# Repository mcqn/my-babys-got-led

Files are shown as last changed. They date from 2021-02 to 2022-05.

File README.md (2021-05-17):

# My Babys Got LED

An ESP8266 board to drive Neopixel/WS2812 LED strips, for plug-and-play use with an ATX power supply. The board is [OSHW certified](https://certification.oshwa.org/uk000030.html
). Latest version now has three injection points with 8A fuses for safety, to manage the high power of ATX power supplies.

See the [My Baby's Got LED product page](https://mcqn.com/ibal223) on the MCQN website for full details.

The finished product is available for sale on Tindie:



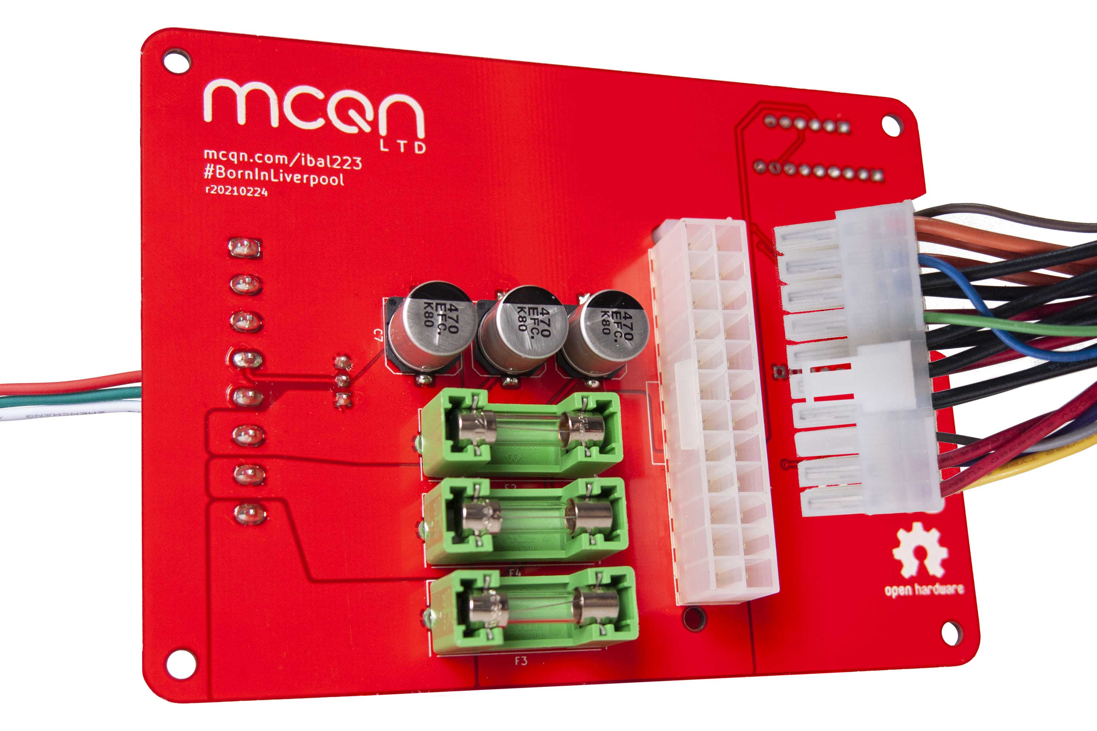
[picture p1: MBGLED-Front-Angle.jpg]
Photo of the finished PCB


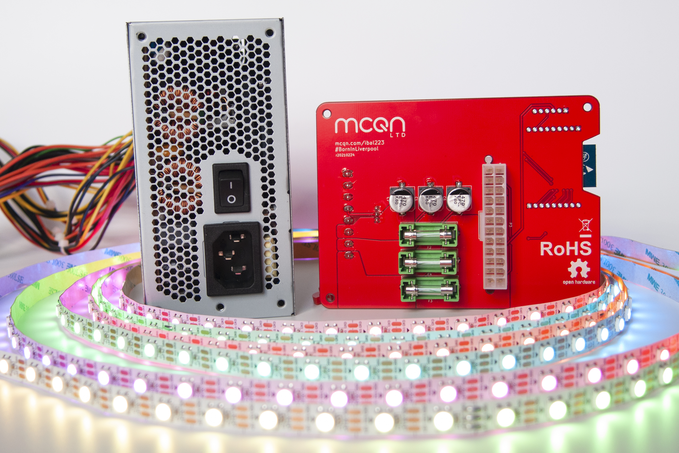
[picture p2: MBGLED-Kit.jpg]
Photo of the PCB with LED strip and ATX power supply


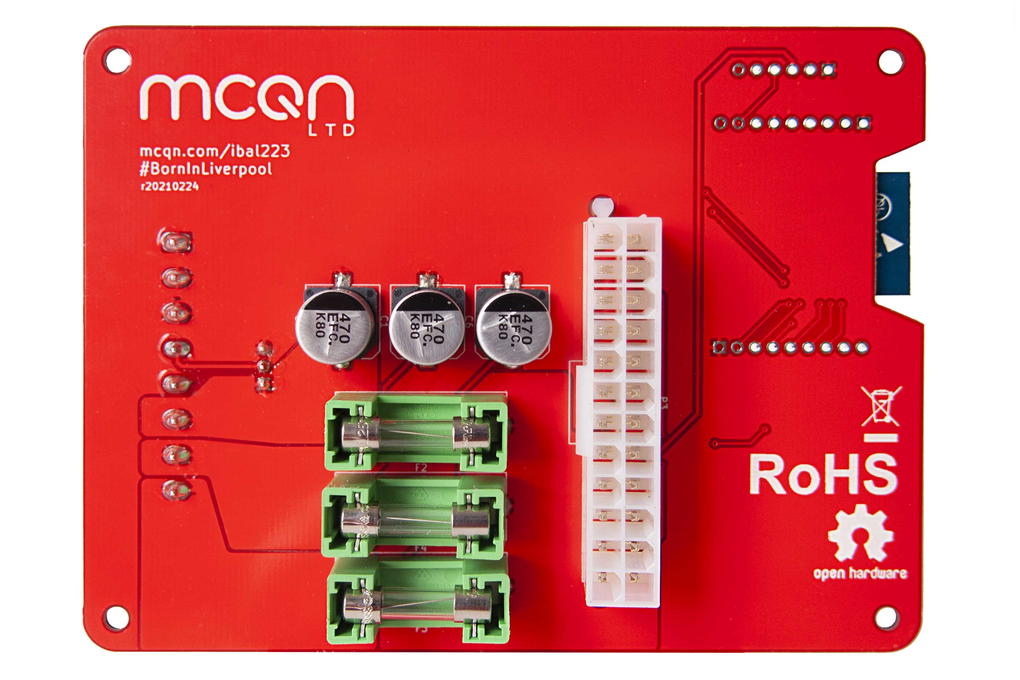
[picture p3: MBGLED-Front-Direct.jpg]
Photo of the front of the finished PCB


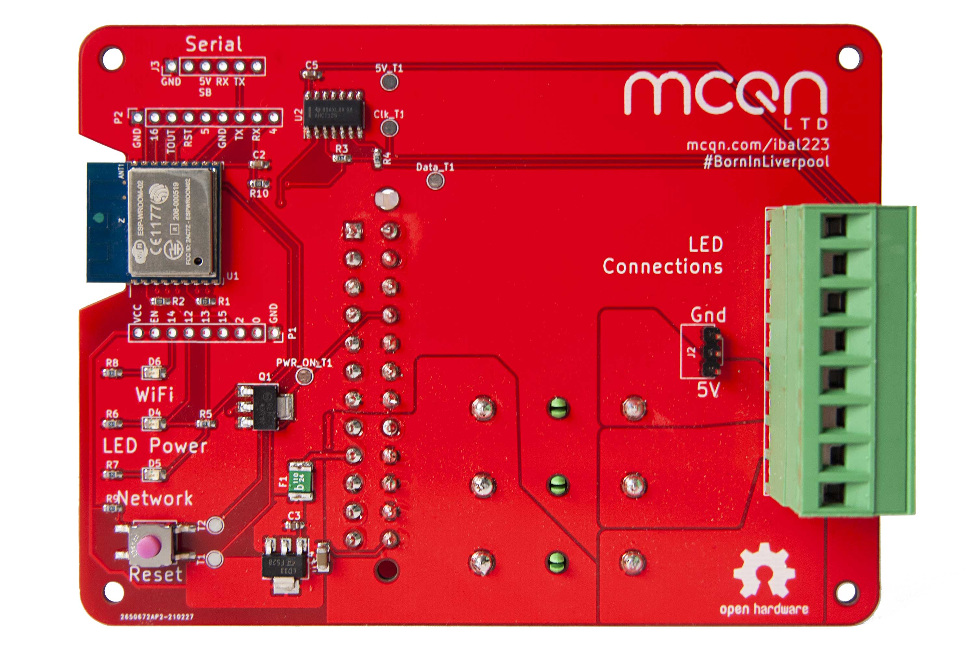
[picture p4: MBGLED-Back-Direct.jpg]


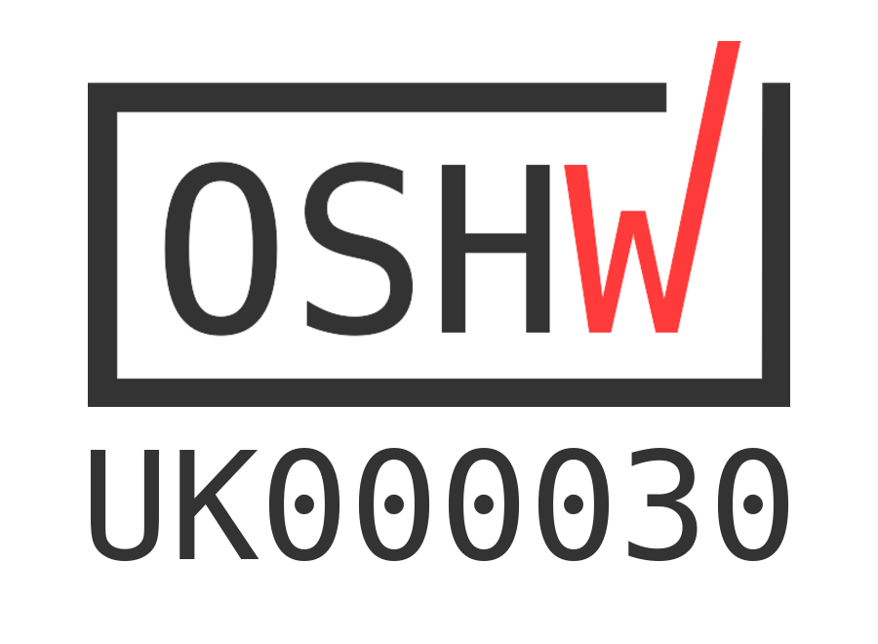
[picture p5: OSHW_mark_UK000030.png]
The open source hardware mark, and the code UK000030


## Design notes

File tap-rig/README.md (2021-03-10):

# Test and Programming Rig

A set-up for a Raspberry Pi plus a jig with pogo pins to make it easier to flash and test a My Baby's Got LED board.

## Steps:

1. Install [Ansible](https://www.ansible.com/get-started) on your computer
1. Install the latest [Raspbian lite image](https://www.raspberrypi.org/downloads/raspbian/) onto a micro-SD card
1. Create a file called `ssh` on the `/boot` partition of the SD card.  The contents don't matter, it's just to enable the SSH server.  E.g. on Ubuntu `touch /media/myusername/boot/ssh`
1. Boot the Raspberry Pi with the micro-SD card, while plugged into a network via Ethernet
1. Find out the IP address of the Raspberry Pi
 * Use nmap (eg: `nmap -p 22 192.168.0.* --open`), router or monitor to find IP address of Pi once booted.
1. Copy your SSH credentials onto the Pi
  ```ssh-copy-id pi@<ip-address-of-the-pi>```
1. Edit the ```hosts``` file so ansible knows which computer to configure.  Change the IP address in it to match the one you just found out.
1. Check you can run commands on the Pi using Ansible
   ```ansible test-rig -i hosts -a "hostname" -u pi```
1. Update the Pi, using the playbook you customised in the last step, e.g.
   ```ansible-playbook test-and-programming-rig.yml -i hosts```

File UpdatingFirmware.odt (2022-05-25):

My Baby’s Got LED Controller Board

mcqn.com/ibal223/

Updating the firmware

To manually update the firmware on the board you will need a USB to serial device.

For example https://uk.rs-online.com/web/p/communication-wireless-development-tools/1501570

If you need to update your firmware and do not have access to an adapter get in touch and we will arrange for you to return the board to us for reprogramming.

Future versions of the firmware will use OTA (Over the air) so you will then be able to update over wifi.

My Baby’s got LED uses user modifications so although you are able to flash the latest release of the WLED directly you will lose some functionality.

https://github.com/Aircoookie/WLED/releases

The preferred method is to use the latest build for My Baby’s got LED and flash using the steps outlined below.

Install esptool.py as described here https://docs.espressif.com/projects/esptool/en/latest/esp32/installation.html

  Download the latest build of the My Baby's got LED firmware
  /my-babys-got-led-firmware-v0.13.1.bin
  Connect your board to your computer using a USB to serial connector and the pins marked 'Serial' on your board.
  NB The connections labelled on your board will match the names on the pins of your USB to serial connector. However the TX and RX pins will be swapped.
  Set the board to programming mode by holding down reset, using a jumper wire to connect P0 to ground and releasing the reset button. P0 and ground can be found in the row of connectors labelled P1 on the My Baby’s got LED board.
  From the command line run esptool.py --before default_reset --after hard_reset --chip esp8266 --port "/dev/ttyACM0" --baud 115200 write_flash 0x0 path/to/my-babys-got-led.bin
  NB Depending on your setup and OS the ‘port’ description may be different. This example shows the typical port description for a Linux OS. In Windows it will be COM[X] and on MacOS dev/cu-usbserial-XXXXX

More Information

There’s lots more information about the WLED software available at

https://kno.wled.ge/

If you have any other questions, drop us a line at info@mcqn.com.

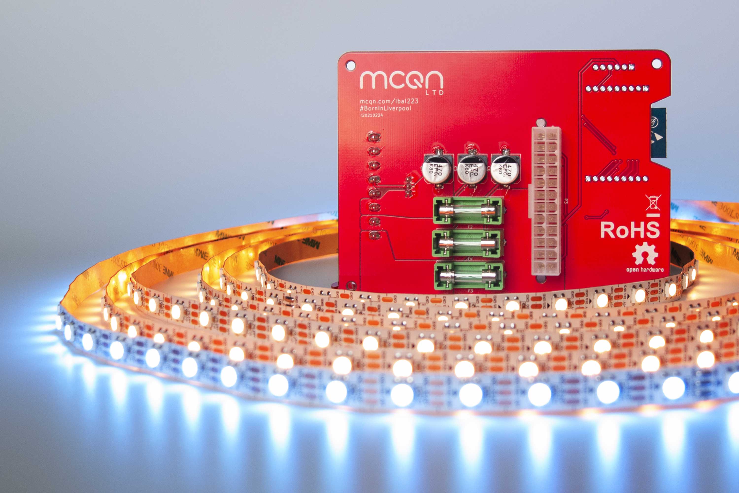
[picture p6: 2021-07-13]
MGBLED-Front-with-LEDs.jpg

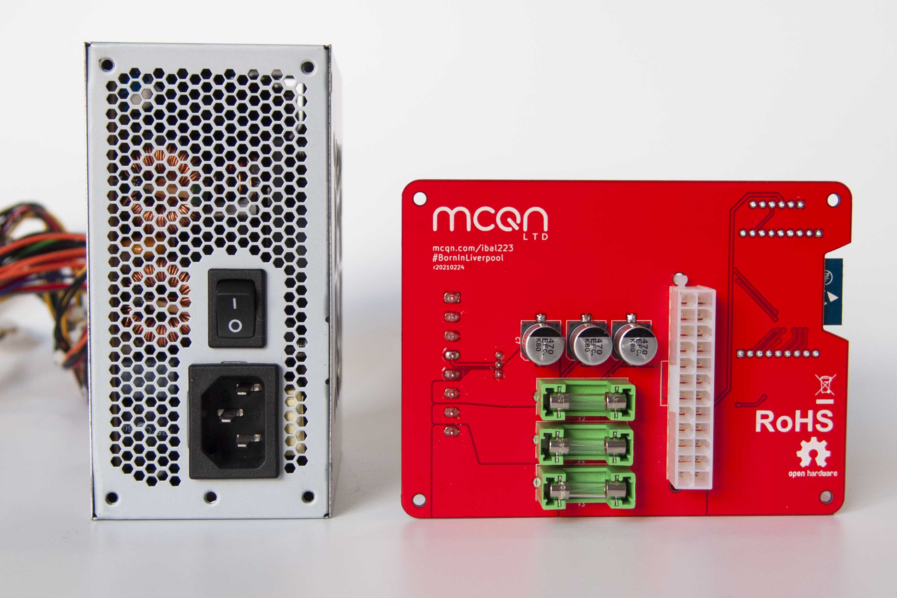
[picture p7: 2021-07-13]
MGBLED-Front-with-PSU.jpg

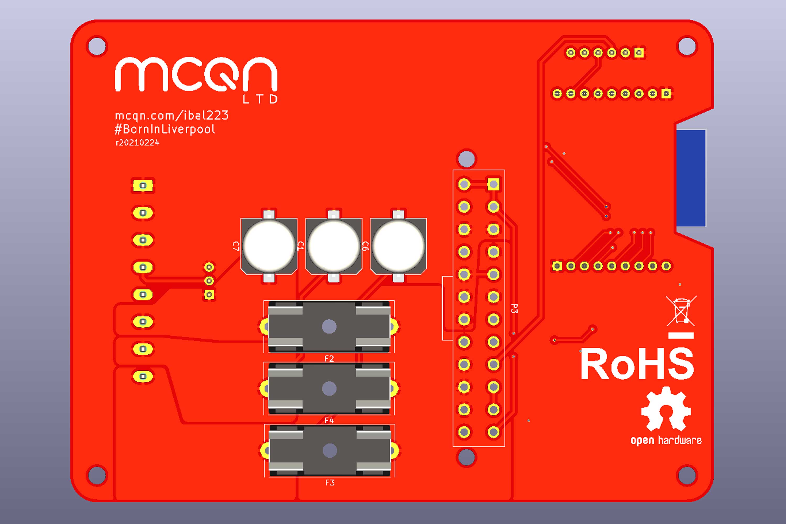
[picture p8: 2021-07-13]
MGBLED-Kicad-Front.jpg

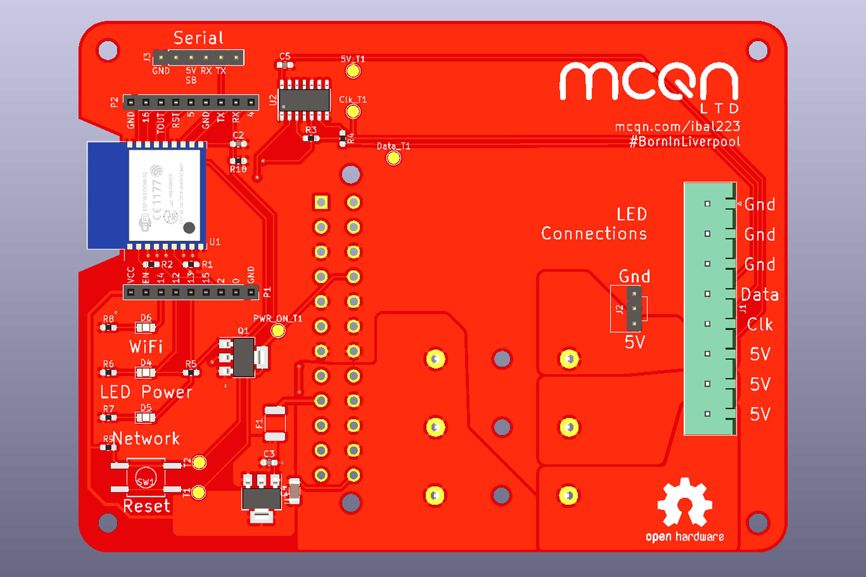
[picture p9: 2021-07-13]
MGBLED-Kicad-Back.jpg

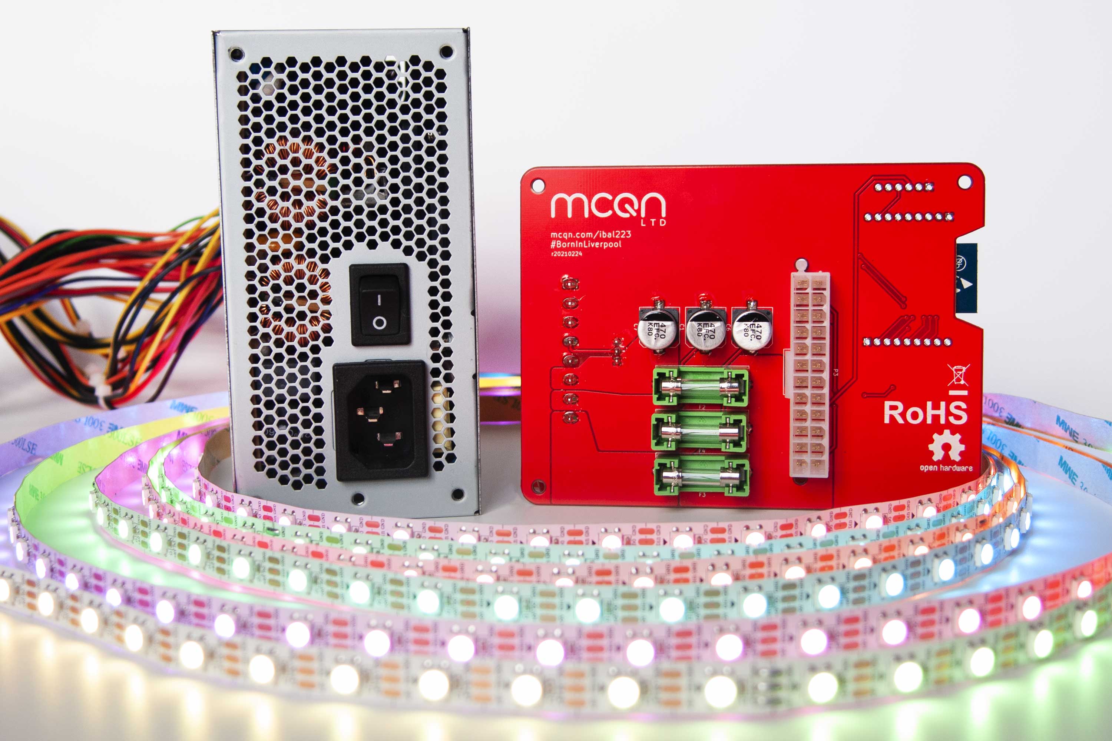
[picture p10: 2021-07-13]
MGBLED-Front-with-PSU-and-LEDs.jpg

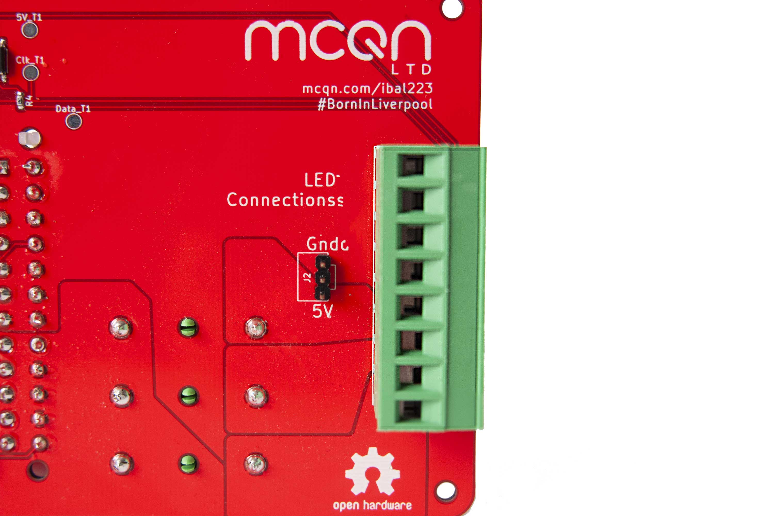
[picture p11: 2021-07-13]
MGBLED-Detail-Power.jpg

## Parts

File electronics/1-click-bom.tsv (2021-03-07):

References | Qty | Description | Digikey | Digikey Price/Stock | Farnell | Farnell Price/Stock | Manuf#
5V_T1, Clk_T1, Data_T1, PWR_ON_T1 | 4
C1, C6, C7 | 3 |  |  |  | 2254313 | https://uk.farnell.com/panasonic/eeefc1e471p/cap-470-f-25v-radial-smd/dp/2254313
C2 | 1 |  |  |  | 1759031 | https://uk.farnell.com/multicomp/mc0603b473k250ct/cap-0-047-f-25v-10-x7r-0603/dp/1759031
C3, C5 | 2 |  |  |  | 1759038RL | https://uk.farnell.com/multicomp/mc0603f104z250ct/cap-0-1-f-25v-y5v-0603/dp/1759038RL
C4 | 1 |  |  |  | 2320887RL | https://uk.farnell.com/multicomp/mc1206x106k250ct/cap-10-f-25v-10-x5r-1206/dp/2320887RL
D4, D5, D6 | 3 |  |  |  | 2290332 | https://uk.farnell.com/kingbright/kp-2012seck/led-0805-250mcd-orange/dp/2290332
F1 | 1 |  |  |  | 1861167RL | https://uk.farnell.com/multicomp/mc36225/fuse-ptc-reset-smd-24v-1-1a/dp/1861167RL
F2, F3, F4 | 3 |  |  |  | 2471681 | https://uk.farnell.com/wurth-elektronik/696107003002/fuse-holder-5x20mm-pcb/dp/2471681
J1 | 1 |  |  |  | 2517883 | https://uk.farnell.com/imo-precision-controls/21-95mv-8-e/terminal-block-header-8pos-th/dp/2517883
J2 | 1 |  |  |  | 1593412 | https://uk.farnell.com/multicomp/2211s-03g/header-1-row-vert-3way/dp/1593412
J3 | 1 | DNP
P1, P2 | 2 | DNP
P3 | 1 |  | WM9738-ND | https://www.digikey.co.uk/products/en?keywords=Molex%2044206-0007
Q1 | 1 |  |  |  | 2533335 | https://uk.farnell.com/on-semiconductor/njt4031nt1g/transistor-bipol-npn-40v/dp/2533335
R1, R2, R10 | 3 |  |  |  | 2331740 | https://uk.farnell.com/te-connectivity/crgh0603j10k/res-10k-5-0-2w-0603-thick-film/dp/2331740
R3, R4, R5 | 3 |  |  |  | 2502462 | https://uk.farnell.com/walsin/wr06x4700ftl/res-470r-1-75v-0603-thick-film/dp/2502462
R6, R7, R8, R9 | 4 |  |  |  | 2502470 | https://uk.farnell.com/walsin/wr06x5600ftl/res-560r-1-75v-0603-thick-film/dp/2502470
SW1 | 1 |  |  |  | 2435308 | http://uk.farnell.com/c-k-components/ksek43g-lfs/tactile-switch-spst-0-05a-32vdc/dp/2435308
T1, T2 | 2 | DNP
U1 | 1 |  |  |  |  |  | ESP-WROOM-02
U2 | 1 |  |  |  | 3006129 | https://uk.farnell.com/texas-instruments/sn74ahct125d/ic-buffer-gate-quad-3state-smd/dp/3006129
U3 | 1 |  |  |  | 1202826RL | https://uk.farnell.com/stmicroelectronics/ld1117s33tr/v-reg-ldo-3-3v-smd-1117-sot-223/dp/1202826RL

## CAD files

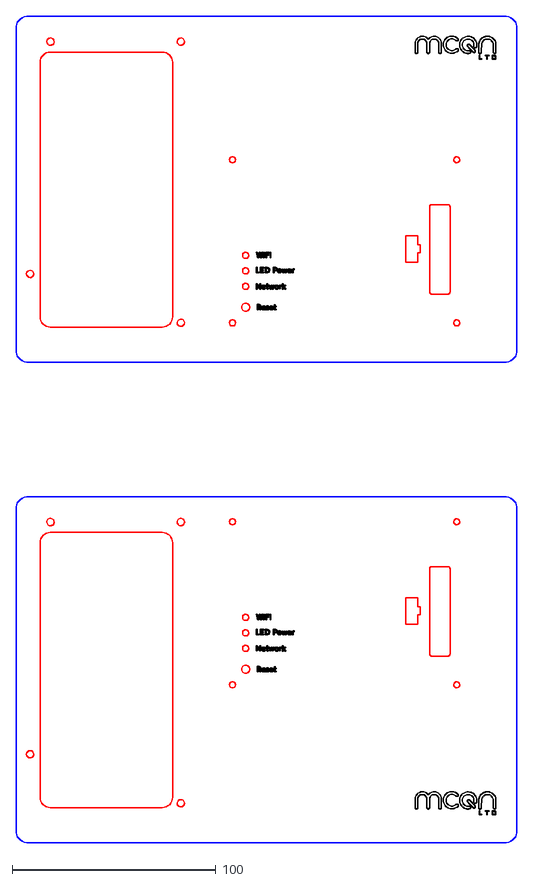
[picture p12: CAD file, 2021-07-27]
mounting-plates/my-babys-got-LED_mounting-plate_PSU-ATX-PS2_dxf-for-laser-cutting.dxf
245.4 x 405.7

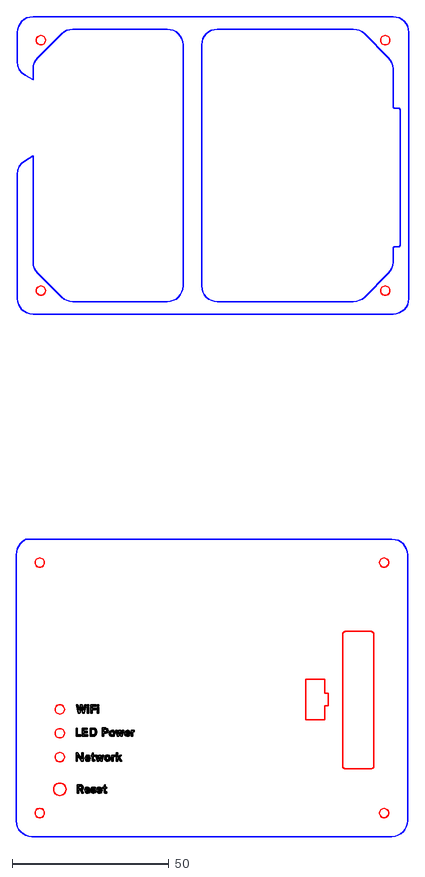
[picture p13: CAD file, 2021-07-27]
mounting-plates/my-babys-got-LED_mounting-plate_one-side-cover_dxf-for-laser-cutting.dxf
125.4 x 261.9

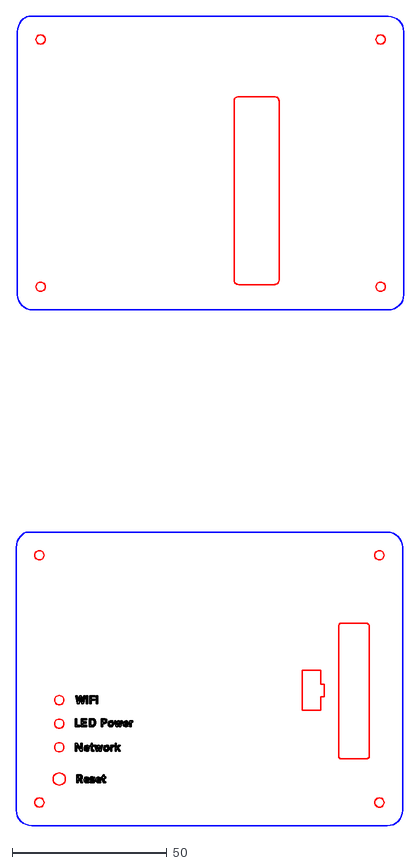
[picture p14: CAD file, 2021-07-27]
mounting-plates/my-babys-got-LED_mounting-plate_sandwich-enclosure_dxf-for-laser-cutting.dxf
125.4 x 261.9

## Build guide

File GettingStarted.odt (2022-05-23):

My Baby’s Got LED Controller Board

mcqn.com/ibal223/

Getting Started

1. Connect your lights to the My Baby’s Got LED controller: either with the 3-pin header, or the green terminal block. Make sure to check the polarity! If you’re running a lot of lights, then use the green terminal block’s 5V and Gnd connections to run extra power lines, in addition to the 3-pin header.
2. Plug your PC power supply into the white Molex connector on the underside of the My Baby’s Got LED controller board.
3. Plug in and power on your PC power supply. The “LED Power” light should illuminate on the controller board; the first 30 LEDs on your LED strip will light up amber; and the “WiFi” light on the controller board will fade on and off.
4. The pulsing “WiFi” light means that the board isn’t connected to WiFi. It will create a new WiFi network called “WLED-AP” with a password of “wled1234”. Connect to that with your phone or computer.
5. You’ll be redirected to the WLED welcome page, from there you can control the lights directly

Connecting the Controller to Your Network

1. Run through the steps in “Getting Started” above.
2. When you get to the WLED welcome page, choose the “WiFi Settings” option.
3. Enter the details of your WiFi so that it can connect to your network (then you’ll be able to control it from any computer/phone on your network) but DO NOT click on save just yet!
4. Find the mDNS setting. You might want to give your controller board a better mDNS name so it’s easier to connect to from your network. At the very least you should make a note of the name, as you’ll need it in a moment.
5. Now you can save the settings by clicking “Save & Connect”.
6. Connect back to your network with your phone/laptop (usually this happens automatically when the controller board turns off the WLED-AP network.
7. In a web browser, go to the name that you made a note of in step 4. If you changed the mDNS name you will need to reset the board by pressing the pink reset button for the new name to take effect.
8. Now you can control the lights as before.

Status Lights

The My Baby’s Got LED controller board has three status lights:

- WiFi – This shows the status of the WiFi connection. If it is solid then the board is connected to WiFi. If it’s pulsing on and off, then the board can’t find the WiFi and has created its own WiFi.
- LED Power – This shows when power is turned on to the LEDs (and when the ATX power supply is turned on, rather than just in standby).
- Network – This shows when the controller has a connection to an MQTT broker, as configured in the “Sync Interfaces” page in the settings.

Factory Reset

Pressing the “Reset” button on the controller will restart the software. If you hold the reset button down for more than 5 seconds it will perform a factory reset, which clears any settings that you’ve added.

More Information

There’s lots more information about the WLED software available at

https://kno.wled.ge/

If you have any other questions, drop us a line at info@mcqn.com.

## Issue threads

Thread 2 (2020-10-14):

Create Kicad component for ATX power supply connector

amcewen, 2020-10-14:
We're going to use an ATX power supply to provide power for it all, as that allows us to reuse existing old computer gear, and should provide enough power for ~500 neopixels (so enough for any individual [geometric light bauble](https://github.com/mcqn/geometric-light)

amcewen, 2020-10-28:
The schematic symbol isn't quite right - it causes complaints in the electrical rules check, which is probably me not quite getting the pin types right.

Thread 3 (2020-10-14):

Design circuit

amcewen, 2020-10-14:
Required features:
 * [x] ATX power supply as the main power source (it has both 5V and 3V3 lines, so should be able to power both the ESP8266 and the LEDs without needing any more conversion)
 * [x] Connector for standard WS2812 LED strips
 * [x] Screw terminal connector for alternative connection options (and easy connecting of additional 5V feeds for long strips)
 * [x] Status LEDs - one for WiFi status, one or two others for other status details
 * [x] Reset button (with long-press for factory-reset - forgetting WiFi details, etc.)
 * [x] Programming header (FTDI-compatible pinout?)
 * [x] Level-shifter for data line (and 100R resistor, to ape the OctoWS2811 board?)
 * [x] Fuse (polyfuse or automotive blade?)

Optional features:
 * [ ] ~~Barrell connector for alternate 5V supply, with a 3V3 regulator to power the ESP8266~~
 * [x] A relay to turn on/off power to the LED strip?

amcewen, 2020-10-28:
One of the status LEDs indicates power to the LED strip, and is connected to the circuitry to turn the ATX power supply on and off.  The ESP8266 is powered via the 5VSB line on the ATX connector, through a regulator, so it'll run whenever the ATX supply has power, and then it fully turns on the ATX supply when the LEDs need to be on (i.e. is wired to the "Power" switch in the WLED software)

Not going to worry about the barrel connector - if I need to repurpose it I can skip adding the ATX connector.

amcewen, 2020-10-30:
The fuse will be a 30A blade type.  Have ordered a bunch of 3-pin connectors to test whether they'll mate with the JST SM connector on neopixels

amcewen, 2020-11-04:
Standard 0.1" pitch headers turn out to be the best option for the WS2812 connector...

Closed 2020-11-04.

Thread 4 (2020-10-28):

Complete BoM and calculate pricing

amcewen, 2020-10-28:
Most of the bill-of-materials details will be in the Kicad file, but there'll be extra things that should be captured somewhere.

* [Pluggable Terminal Block, 5.08 mm, 4 Ways, 28AWG to 14AWG, 1.5 mm², Screw, 17.5 A](https://uk.farnell.com/imo-precision-controls/21-950m-4-e/tb-pluggable-4pos-28-14awg/dp/2575235)

amcewen, 2020-10-30:
Also a 30A blade fuse, and the PCB (or PCBA) itself

amcewen, 2020-11-07:
Pricing set at £42.

Closed 2020-11-07.

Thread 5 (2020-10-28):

Lay out PCB

amcewen, 2020-10-28:
Lay out the PCB from the circuit in #3.  Additional things to consider/remember:

 * [x] Add mounting holes
 * [x] Add OSHW logo
 * [x] Add product URL
 * [x] Silkscreen to label FTDI connections
 * [x] Silkscreen to label LED connections
 * [x] Ensure there's enough space between the two LED connectors to fit the pluggable screw terminal in

amcewen, 2020-11-06:
All done, and the initial batch of PCBs ordered!

Closed 2020-11-06.

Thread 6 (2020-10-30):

Test circuit with Dotstar LEDs

amcewen, 2020-10-30:
There is support for the 4-wire APA102 LEDs too.  Need to test it before finalising #3 (should also check the pin-out for the APA102 strips to ensure it matches the 4-pin screw-terminal connector)

amcewen, 2020-11-04:
Needs different firmware, but works fine!

Closed 2020-11-04.

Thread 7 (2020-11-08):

Build a mounting board

amcewen, 2020-11-08:
Given ATX power supplies have a standard set of mounting points, we could laser-cut a nice board that mounts to the power supply and then provides suitable mounting points for the PCB, to keep everything together more neatly.

arthurrowland, 2021-05-10:
Given we've seen that there is quite a lot of variation in ATX mounting, shall we adapt this issue to be just for mounting the board itself, and the user can adapt to their own supply and situation?

arthurrowland, 2021-06-14:
I prepared this one-side board with two layers of 4mm MDF and M3x12 bolts. Would need etching to be useful. It's quite satisfying to hold and for casual applications the molex cable works fairly was as a stand to hold it at a useful angle. Don't love it, but is quite inexpensive to produce.

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

arthurrowland, 2021-06-21:
Following an in-person discussion with @amcewen, I have been looking at the many PSU mounting patterns to scope out how many we might want to draw up, if any, beyond the 'standard' ATX mounting pattern.

Here's a really good summary of the different types of ATX power supplies, with the mounting patterns and external dimensions clearly visible:
http://www.evercase.co.uk/index.php?route=information/information&information_id=7

Here are the most common power supplies stacked, with an adaptor plate on the top SFU-type PSU.

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

Here's a drawing for the cutout for SFX type PSUs found [here](https://www.overclock.net/threads/official-usff-sff-club.1300645/page-76):

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

and here's the ATX one while we're at it, since it's not already linked in this issue:

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

- Option 1: No mcqn support for SFX type
- Option 2: Design mounting plate with both sets of holes
- Option 3: Supply separate mounting plate for SFX
- Option 4: Supply adaptor plate for SFX to ATX - for example [£4 on ebay](https://www.ebay.co.uk/itm/154474553329) and [£2 on alibaba](https://www.aliexpress.com/item/1005002011841397.html)
- Option 5: Flag mounting issues and link people to adaptor plates <- most pragmatic option in my view

Next steps are to update the small board protector to become a sandwich-style case and add some simple outline labels, and update the PSU panel mount version with the latest, larger, revision of My Baby's Got LED.

arthurrowland, 2021-07-13:
I have [renamed](https://github.com/mcqn/my-babys-got-led/commit/b23c36c1570613539b88990fc99c7ff27c7890fe) the ATX PS2 mounting board files ([twice](https://github.com/mcqn/my-babys-got-led/commit/a32d96c2b49a5abdc0e383e5d23d10f2a5657efc)) and included the design files for the following enclosure (rough prototype from scavenged acrylic, but dimensions are correct).

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

It uses 20mm standoffs on the molex side and 10mm standoffs on the LED/status light side.

The new file names distinguish between rev1 and rev2 my baby's got LED boards and the PSU mounting patterns (where needed).

Closed 2021-07-27.

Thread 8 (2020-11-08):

Document the supply chain

amcewen, 2020-11-08:
Like we did for the Ackers Bell, it would be good to create a supply chain map.

It'd be even better if it could be created programmatically from the BoM...

amcewen, 2021-05-20:
Here's an [interesting thread looking at Apple's supplier list](https://news.ycombinator.com/item?id=18199170).  From there, there's the [Marks and Spencer supplier map](https://interactivemap.marksandspencer.com/), [someone digging into the Apple list and sharing their code](https://github.com/ssobczak/apple_suppliers), and [a bunch of guides from Adidas on their supply chain standards](https://www.adidas-group.com/en/sustainability/reporting/policies-and-standards/)

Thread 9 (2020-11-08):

Apply for OSHW certification

amcewen, 2020-11-08:
Given it's open hardware, we should get the OSHWA certification for it.  https://application.oshwa.org/apply

amcewen, 2021-02-10:
What license is the documentation under?  Having run through the CC licence chooser, it will be [CC BY-SA 4.0](http://creativecommons.org/licenses/by-sa/4.0/?ref=chooser-v1).  We should add the documentation to the Github repo.

Do we need to change licence for the board itself (i.e. is AGPL not the right choice - CERN, Solderpad or TAPR are the named choices on the OSHWA application)? https://certification.oshwa.org/process/hardware.html gives a brief overview of those hardware licences.

From that guide, the *rough* mapping from software -> hardware is GPL -> CERN; Apache -> Solderpad; GPL -> TAPR (which can also cover documentation).

Reading through it, the CERN-OHL-S v2.0 is the most applicable, so I've updated the licence for that.

arthurrowland, 2021-05-10:
May as well open source the whole application process, reproducing the application form currently hosted at this URL: https://application.oshwa.org/apply

- [ ] @arthurrowland drafted
- [ ] @amcewen updated/approved
- [ ] @arthurrowland applied

**BASIC INFORMATION
SECTION 1 OF 4**
This part of the form asks for basic information about the responsible party for the project to be certified, such as the name of the individual, company, or organization certifying the project and contact information for any future correspondence from OSHWA regarding your certification.

This certification is on behalf of a: Company
Name of Individual, Company, or Organization Responsible for the Certified Item: MCQN Ltd
If not an Individual, name of Individual with Authority to Bind the Company or Organization: Adrian McEwen

**Contact Information**
Country: United Kingdom
Street Address Line 1: DoES Liverpool, The Tapestry
Street Address Line 2: 68-76 Kempston Street
City/town/village: Liverpool
State/Province/Region: Merseyside
Zip code/postal code: L3 8HL
OSHWA Contact Email Address: redacted
Public contact email address: info@mcqn.com

**PROJECT INFORMATION
SECTION 2 OF 4**
This part of the form asks for information about the project you wish to certify. Information submitted here will appear on your project’s profile listing.

Project name: My Baby's Got LED
Project version: 1.0
Have you previously registered a version(s) of your project with OSHWA? No
Project description: My Baby's Got LED is an LED driver board using WLED to drive individually addressable LEDs at 5V, using an ATX power supply. It uses an ESP8266 chip and can be controlled using its own WiFi network or by connecting to an existing network. The development and documentation for the board is available on github, and the board is manufactured by mcqn and sold on Tindie.
Project website: mcqn.com/ibal223
Primary Project Type: IOT
Additional Project Types: Arts, Electronics, Home Connection
Project Keywords: WLED, MQTT

Where can the documentation be found for your project?: https://github.com/mcqn/my-babys-got-led

Does your project incorporate or build upon other open projects that are not currently certified by OSHWA? If so, use this space to cite those projects

| Citation Title | Citation URL |
| --------------- | --------------- |
| WLED | https://github.com/Aircoookie/WLED |

**LICENSING INFORMATION
SECTION 3 OF 4**
This part of the form asks for information about your project’s licensing. In order to qualify for OSHWA certification, you must have chosen an open source license for your hardware, your software (if any), and your documentation. Your licenses for each of these elements will appear on your project’s profile listing.

What license is your project's hardware licensed under? CERN
What license is your project's software licensed under? @amcewen is this GPL?
What license is your project's documentation licensed under? CC BY-SA

| Statement | Response | Explanation |
| --------------- | --------------- | --------------- |
| The project is licensed in a way to allow for modifications and derivative works without commercial restriction. | Yes | |
| There is no restriction within my control to selling or giving away the project documentation. | Yes | |
| Where possible, I have chosen to use components in my hardware that are openly licensed. | Yes | |
| I understand and comply with the "Creator Contribution requirement," explained in the [Requirements for Certification](https://certification.oshwa.org/requirements.html). | Yes | |
| There is no restriction on the use by persons or groups, or by the field of endeavor. | Yes | |
| The rights granted by any license on the project applies to all whom the work is redistributed to. | Yes | |
| The rights granted under any license on the project do not depend on the licensed work being part of a specific product. | Yes | |
| The rights granted under any license on the project do not restrict other hardware or software, for example by requiring that all other hardware or software sold with the item be open source. | No | CC-BY-SA requires adaptions of the documentation use the same license. @amcewen what about the other licenses? |
| The rights granted under any license on the project are technology neutral. | Yes | |

CERTIFICATION
SECTION 4 OF 4
This part of the form asks you to certify that you agree to specific terms of the [OSHWA Certification Mark License Agreement](https://certification.oshwa.org/license-agreement).

You agree to the following terms:
- [x] I have provided OSHWA with accurate contact information, recognize that all official communications from OSHWA will be directed to that contact information, and will update that contact information as necessary.
- [x] I will only use the certification mark in compliance with official certification guidelines.
- [x] I acknowledge that all right, title, and interest in the certification mark remains with OSHWA.
- [x] I acknowledge that OSHWA has the right to enforce violations of the use of the mark. This enforcement may involve financial penalties for misuse in bad faith.
- [x] I have the ability to bind those responsible for the certified item to this agreement.

If you do not agree with any of the above terms, please explain.
Provide a brief explanation (500 characters)
Relationship to certified item: I am the primary developer of the certified item, as well as a manufacturer and retailer of the item as a commercial product.

- [x] I agree to the terms of the OSHWA Open Source Hardware Certification Mark License Agreement, including the Requirements for Certification and Usage Guidelines incorporated by reference and including license terms that are not present in or conflict with this web form. I acknowledge that by agreeing to the terms of the OSHWA Open Source Hardware Certification Mark License Agreement that I am binding the entity listed to the License Agreement. I recognize that I will receive my unique identification number that allows me to promote my project as OSHWA Open Source Hardware Certified in compliance with the user guidelines via the email provided to OSHWA after submitting this form.

If you are the parent or legal guardian entering into this agreement on behalf of an individual under the age of 18, please provide your name to certify that you also agree to be bound by this agreement.: Not applicable.

amcewen, 2021-05-10:
According to [the LICENCE file in WLED](https://github.com/mcqn/WLED/blob/master/LICENSE) it's MIT.

So the software can be used in other non-open projects, but the hardware is restricted under the CERN Open Hardware Licence Version 2 - Strongly Reciprocal.

It's not v1.0.  Checking the board, we've only got a revision number.  I should maybe have included a version number, but at present I think `r20210224` is the best version indicator we've got.

We probably need to document the documentation licence somewhere...

amcewen, 2021-05-10:
LGTM :+1:

arthurrowland, 2021-05-10:
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

arthurrowland, 2021-05-24:
We did it!

https://certification.oshwa.org/uk000030.html

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

Closed 2021-05-24.

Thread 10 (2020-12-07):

Test board with high current draw

amcewen, 2020-12-07:
Run a soak test with lots of LEDs so that we can check its operation at high current use.

amcewen, 2020-12-07:
I set up a test with a 500W ATX power supply that can provide 30A at 5V (according to its spec) driving 608 LEDs, set to full brightness and white so it was using a (calculated) 30A.

Left the system on for seven hours, keeping an eye on it and periodically taking temperature readings of the PCB:

| Time | PCB by fuses top-side | PCB by fuse bottom-side | Terminal block |
|---|---|---|---|
| 11:00 | 38 | 40 | 31 |
| 11:30 | 38 | 40 | 23 |
| 12:30 | 35 | 38 | 26 |
| 15:00 | 35 | 44 | 35 |
| 18:00 | 38 | 42 | 33 |

The board got warm to the touch pretty quickly, but then stayed at that temperature for the rest of the day.  Which is all good.

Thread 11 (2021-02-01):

Improve packaging

amcewen, 2021-02-01:
So far all the orders have gone out in (reused, to offset the plastic in them...) padded envelopes, but it'd be good to have something sturdier.

Most likely that'll be an off-the-shelf cardboard box, with brown paper padding.  Maybe there's a simple laser-cut insert and/or laser-cut embellishment to the boxes to improve the looks?  Or some custom packing tape, or stickers to use to seal the boxes, or...?

amcewen, 2021-03-03:
I've been collecting (possibly) useful [packaging](https://pinboard.in/u:amcewen/t:packaging) links on my Pinboard account.

The Post Office [small parcel pricing](https://www.postoffice.co.uk/price-finder) is for parcels below 35x45x16cm in size.  Something thin enough to go through a letterbox is probably a sensible approach too, if possible.  [This page on standard European letterbox sizes](https://www.safe.co.uk/safezone/2011/09/the-european-standard-for-letter-boxes/) suggests:
> an aperture width of either 230–280 mm (> C4 width) or 325–400 mm (> C4 height); an aperture height of 30–35 mm

amcewen, 2021-03-08:
The populated board is 45mm tall, so we can't do a letterbox-friendly version (unless we ship the screw terminals block not plugged in, but it'd be better not to, I think).

We need to hold 120x90x45mm.  I've ordered a few sample sizes, so we can pick whichever works best.

amcewen, 2021-03-22:
All of the sizes are fine, we'll be using 130x130x65mm boxes for now (as that's what we've got most of in the samples)

Closed 2021-03-22.

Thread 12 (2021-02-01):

Rework the Electric Liverbird in DoES Liverpool to use a My Baby's Got LED board

amcewen, 2021-02-01:
The [Electric Liverbird](https://mcqn.com/ibal145/) in DoES Liverpool currently has a Raspberry Pi and Arduino and custom power supply to drive its Neopixels.

It'd be a good candidate to convert to a My Baby's Got LED board to show what's possible, and use the segment support for different parts of the bird: beak; newspaper; legs; head; wing...

Then we could get the MQTT integration working to animate it more in DoES Liverpool.

amcewen, 2021-02-12:
The Electric Liverbird has WS2801 LEDs in it, so requires a special build of `WLED` with `USE_WS2801` defined.  We got it upgraded today and it's up and running.  There's a bit of tidying up still to do:
 * [ ] Replace the fuse with a 10A, because there are only 150 LEDs in it, so it won't need any more
 * [ ] Crimp bootlace ferrules onto the wires in the screw terminals
 * [ ] Box up the board and power supply
 * [ ] [BONUS] Provide a 5V supply for the LED matrix display, given Julian had been powering it from a spare USB port on the old setup

amcewen, 2021-02-26:
Looks like there's a new feature in WLED (I'm pulling the latest changes in at the moment to update our fork) which [might make it easier to map the Liverbird LEDs to useful segments](https://github.com/Aircoookie/WLED/commit/2544d2e0680d4fd27ae3741bb773d9e513e42b0d)

arthurrowland, 2021-05-10:
We still achieved a decent outcome even with the board floating loose: https://mcqn.com/posts/doestheliverbirdplay-connecting-twitter-to-wled-to-find-out/

Shall I box it up tomorrow in a simple birch ply thing? Any unusual specifications?

amcewen, 2021-05-10:
That sounds like a plan.  It'd be good to etch the photo of the Post and Echo building (featuring the Liverbird in its original home) onto the front of the case again, with the "The Electric Liverbird" and credits text.  The original electronics box design is in the LiveRGBird repo on the MCQN server.

I've ordered [one of these USB A sockets](https://uk.farnell.com/tuk/kua2whpm/usb-conn-2-0-type-a-rcpt-wht/dp/3367486) too, so we can provide a 5V power supply for the coffee age display.

amcewen, 2021-05-10:
IKR.  I would've bought one with a better datasheet, but didn't find any at a reasonable price.  It should turn up tomorrow anyway, so shouldn't slow things down too much.

I don't have any strong opinions on box generation.  Whichever you prefer.

arthurrowland, 2021-06-29:
I used the [universal box generator](https://festi.info/boxes.py/UniversalBox) from boxes.py with the following settings, for nominal 4mm MDF and an ambitious burn setting.

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

It was very tight going together, probably because the material was actually 4.22mm, though that would have already been factored into the [burn test](https://festi.info/boxes.py/BurnTest) I ran before cutting the main box.

I seem to have lost my touch when it comes to etching - poor results on both MDF and Plywood (not pictured - had hoped to put a nice cut-out panel of the main image on top of the MDF).

Anyway it's a workable enclosure, but I couldn't get the Liver bird to power on using the terminals. Figured it would be quicker overall to wait for @amcewen input rather than poke about with it.

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

arthurrowland, 2021-06-30:
We're almost there!

I replaced the side panel and fitted the same rev1 board back into position.

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

There's a video of part of the build here: https://twitter.com/MCQN_Ltd/status/1410218247572668419

Do we want to publicly document how to play with it using node-RED, here or over on the DoES github? Both? Neither?

@amcewen where is the matrix display mentioned early in this issue? Strictly this issue is just to provide the port, but it feels like we need to plug it in to close it off properly :)

Closed 2021-07-05.

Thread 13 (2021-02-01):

Document extracting a PC power supply

amcewen, 2021-02-01:
Possibly for use in #12, we should film a short video of opening up an old PC and pulling out the power supply to use with a MBGL board.

arthurrowland, 2021-05-10:
Is there any situation where neopixels can be scavenged, to mirror the process on the other side of the board?

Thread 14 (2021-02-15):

Run some tests with the power lines shorted

amcewen, 2021-02-15:
In addition to the high current draw tests we ran in #10, it would be good to test the worst-case scenario of shorting the power line.

Tests to run:
* [x] Power to ground shorted on the screw terminal block, with a thick cable
* [x] Power to ground shorted on the screw terminal block with cable typical of Neopixel connectors
* [x] Power to ground shorted on the "JST" connector, with cable typical of Neopixel connectors
* [x] Power to ground shorted on a strip of Neopixels (with a solder bridge?)

It would be useful to test with a range of currents running through the "shorts", so we can build a test rig which lets us approach the limits more gradually.

amcewen, 2021-02-15:
Bought a bunch of 1ohm, 30W resistors last week to allow stepped current tests.

Tried it on Friday - the resistors heat up lots, and often fail, just used on their own.  Hooking up an ammeter showed that the resistance increased a fair bit as the resistor heated up - with a single resistor the initial current would be around 4A, and then drop pretty rapidly down to ~1.7A.  Adding a beefy heatsink to the resistor, and it settled down to 3.8A, but that's a way off 5A and would make a much harder build to step up resistors in parallel.

I think the next step would be to try 100m of 1.5mm^2 cable, which should have a 1ohm resistance, and handle 28A.  Then we can shorten the length to reduce the resistance and increase the test current.

amcewen, 2021-02-15:
### Complete set up
Running through the JST connector, onto a strip of twelve IP68-rated (so sleeved and potted) WS2812B LEDs, with the far end of the strip shorted through a varying length of 1.5mm<sup>2</sup> cable
| Length | Current | Notes |
|---|---|---|
| 50m | 6.24A | JST and wires stayed at room temperature.  Strip itself was warm to touch - measured 30&deg;C after 15 minutes and steady at that still at 20 minutes and half an hour |
| 35m | 7.8A | 15 mins in - JST and wires at 24&deg;C, strip at 30-38&deg;C, the same after 30 minutes.  The end of the strip, which was exposed to air rather than sleeved and potted, was sat at 14&deg;C |
| 15m | 12.15A | after a couple of minutes the wires from the JST connector to the strip started to smoke a little.  A few of the LEDs in the strip turned red around then too - they seem okay when they've cooled down
| 25m | 10.2A | had LEDs go red almost immediately, but that could be because they'd been damaged in the previous test.  5 mins in JST at 30&deg;C, strip at 46&deg;C, same after 14 minutes, and after 30 minutes, and still after an hour.  Test stopped then. |

amcewen, 2021-02-24:
Started long-running 25m/10A test at 11:10am last Friday
* 5mins in - strip at 44&deg;C, wires at 36&deg;C
* 15mins in - strip at 50&deg;C, wires at 36&deg;C
* 45mins in - strip at 52&deg;C, wires at 32&deg;C
* 3 hours in - strip at 52&deg;C, wires at 32&deg;C
* 5 hours in - strip at 52&deg;C, wires at 33&deg;C

amcewen, 2021-02-24:
10:15am, started test powered by the 550W power supply rated at 32A of 5V with just a 25m length of wire, which should give 0.25ohm resistance and so give 20A current through the circuit.  That's too high for the ammeters available to measure.  The voltage across the wire is 4.33V, and the resistance measured of 0.1 ohms on the handheld meter and 0.5 ohms on the bench meter.

* 10 mins in, PCB at 32&deg;C at the point where the fuseholder is soldered in
* 1 hour in, PCB at 33&deg;C

Switched to a higher current at 11:15am, with a 15m length of wire (with a measured 0.1 ohm resistance, but the meter doesn't read a second decimal place in that range, so could have been the more expected 0.15 ohms, the bench meter claimed 0.3 ohms).  The voltage across the wire was 3.9V,

* 10 mins in, PCB at 40&deg;C
* 45 mins in, 43&deg;C
* 1 hour 15 mins in, PCB at 43&deg;C
* 2 hours in, PCB at 44&deg;C
* 3 hours in, PCB at 37&deg;C
* 4 hours in, PCB at 40&deg;C
* 5 hours in, PCB at 42&deg;C
* 6 hours in, PCB at 43&deg;C

amcewen, 2021-02-26:
Board mods for better power management and some improved testing while we're at it:

* Three 5V/Gnd feeds rather than one, each protected with a 5x20mm 8A fuse
* 470uF smoothing caps on the 5V lines, rather than a single 1000uF
* New test points for 5V, data and clock lines

Closed 2021-02-26.

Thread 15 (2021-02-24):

Build a programming/testing rig

amcewen, 2021-02-24:
To make programming easier, and to allow simple (initially) testing it would be useful to have a programming/testing rig.

This can use the [openfixture](https://tinylabs.io/openfixture/) setup with some pogo pins for the jig, hooked up to a Raspberry Pi.  A physical interface with `short test` and `full test` buttons, coupled with obvious red/green failed/passed indicator lights would be good, but we can start with running something from the command line when `ssh`ed into the Pi.

## Short Test
This would program a board and run the tests we'd do before shipping it
1. Pull latest code
2. Build code
3. Short pin 0 to ground
4. Power up the board, so it goes into programming mode
17. Record the MAC address for the board (get this info as early as possible, obviously so we can log results against it)
5. Program the board over serial
6. Reset board
7. Check that the LED strip is functioning (have a few LEDs connected via the test pads?  Parse the data from the test pads directly?)
8. Check that the LED power status LED is lit
8. Look for `WLED` WiFi access point
9. Connect to the WiFi access point
10. Change the colour of the LEDs with the web UI
11. Configure WiFi settings
12. Check that the WiFi status LED goes solid
13. Check that the `WLED` WiFi access point is no longer present
13. Turn power off via the web UI
14. Check that the LED power status LED goes off
15. Set MQTT settings via the web UI
16. Check that the Network status LED goes on
18. Perform factor reset on the board
19. Check that Network status LED is off
20. Check that LED strip is reset to default colour
21. Check that `WLED` WiFi access point is present again
22. Log the results - MAC address, software version, test results
23. Power off board
24. Illuminate pass/fail indicator

## Long Test
This is more to test the latest version of the software, as part of a CI setup.  It would run through the `Short Test` procedure and add additional tests in between steps 19 and 20 to exercise the software more.

amcewen, 2021-06-19:
Got the Ansible script finished (I expect) for building and uploading with Platform.IO.  Running `platformio run -v -e nodemcuv2 -t upload --upload-port=/dev/ttyAMA0` will compile and upload the code to a board, but takes ~7 minutes, so I think we should split it into a `platformio` command to build the code, and then a separate "upload prebuilt binary" running outside of Platform.IO so it doesn't spend an ages checking through dependencies.

amcewen, 2021-06-23:
Building the full image from scratch on the Pi took 174 minutes in the test I just ran, so we should do that less often than for every upload :grin:

Uploading with `esptool.py --port /dev/ttyAMA0 write_flash 0x00000 build_output/firmware/travis_esp8266.bi` takes 59 seconds, so that's much  better for the upload script.  I'm not sure all the parameters are correct for that `esptool.py` upload though, as the board doesn't seem to be running the code once it's uploaded.

amcewen, 2021-06-28:
`esptool.py --before default_reset --after hard_reset --chip esp8266 --port "/dev/ttyAMA0" --baud 115200 write_flash 0x0 WLED/build_output/firmware/my-babys-got-led.bin` seems to successfully upload the code.

Building the platform.io `buildfs` target doesn't seem to compile everything, so I'm not sure how to build it without also trying an upload at the end (I'm probably missing something)

amcewen, 2021-08-11:
Tested the rig from #21 and it's working nicely.

Had problems with the power switching, have spun that out as #24.  Also worked out that the Pi is *far* too slow to build the software for doing any debugging using it :grin:

amcewen, 2021-08-13:
Have ordered some 4N35 opto-isolators to allow wiring up the reset button to the Pi.

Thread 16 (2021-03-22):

Improve the Getting Started instructions

amcewen, 2021-03-22:
While we've got some basic instructions that are included with each board, it would be better if...
* [ ] ...they were in a format better suited to inclusion in our boxes
* [ ] ...we included some notes on running multiple power feeds

arthurrowland, 2021-03-26:
- [ ] included information about the smartphone app

arthurrowland, 2021-05-10:
- [ ] Consider including mdns scanner app to find IP address

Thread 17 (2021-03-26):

Add something to the silkscreen to show which GPIOs are used by the rest of the board

amcewen, 2021-03-26:
It would be handy for anyone wanting to use the breakout headers for the ESP8266 if there was an indication of which ones were already wired to other parts of the board.  We should update the silkscreen to make that clearer.

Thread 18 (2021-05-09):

Create some tutorials on how to use MBGL/WLED to do interesting things

amcewen, 2021-05-09:
In the same way that we [recorded a LiveCoding session for connecting the Electric Liverbird to Twitter](https://www.youtube.com/watch?v=6vbz_RKSmfA, we should make some more guides to how to use the MBGL boards to do cool stuff.

We can note possible ideas here...

* [ ] Using https://github.com/scottlawsonbc/audio-reactive-led-strip to build a WLED VU-meter
* [ ] Building on that last one, setting up a Pi as a dedicated VU-monitor (would be handy in the [DoES Liverpool](https://doesliverpool.com) event room, hooked up to the PA...)
* [ ] A tide clock, so you can pick the right time to go walk the dog
* [ ] Ditto but so you can catch the sunrise/sunset ([this seems a decent JSON API for the Liverpool times, for example](https://api.sunrise-sunset.org/json?lat=53.4143&lng=-2.9807)

amcewen, 2021-05-10:
Maybe try out https://github.com/atuline/WLED/wiki/Analog-Audio-Input-Options as an alternative option for sound-reactive that doesn't require an additional computer/Pi (but does need a microphone/line-in circuit to be wired into the board)

arthurrowland, 2021-05-10:
Uh oh, I've had an idea... A vision of a warm, dusky summer evening gig in the park by a friendly band, with some IP rated LED strips surrounding the band reacting to the music. Whether we want to resource that vision is another thing! If the gig was 3 hours long and the board was drawing 24A (restricted by the fuses), we get a requiredment of 24,000mAh which is within reach of something [like this 3-pin power bank](https://www.ebay.co.uk/itm/184460937085) if we can borrow one. Day trip for the geometric lights? Or best kick this into the someday/maybe pile?

amcewen, 2021-05-10:
Hehe, well... on Friday's ride Danny was pitching his plans for some short gigs in them sometimes, which did lead me into wondering about some lights for it.  I don't think it's a priority, but might be worth a bit more back-and-forth over the coming months.

arthurrowland, 2021-05-10:
Even better! Will let it simmer.

amcewen, 2021-08-23:
Create a few #Cheerlights-based MQTT channels, so people can easily set their board up to do cheerlights at Christmas

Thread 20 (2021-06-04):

Write up how to update the firmware on your board

amcewen, 2021-06-04:
Some of our users will want to update the software, so we should write a short guide (or point them at the relevant bit of the WLED wiki).

There'll be two options:
 * Using the OTA update to do it over WiFi (we should test that it works too - I've not tried it yet)
 * Using an FTDI (or similar) cable

We'll need to publish releases of our version of WLED (the only difference being the couple of usermods for the status LEDs and factory reset option) for people to be able to easily get a new version, rather than having to build their own (but I guess we should add a "build from source" section to the reflashing guide too)

arthurrowland, 2021-08-18:
Using [this .bin file (zipped)](https://github.com/mcqn/my-babys-got-led/files/7008084/my-babys-got-led-WLED-20210818.zip), here are the steps I followed to successfully update the board I'm using for the Totaliser. Unfortunately it failed while I was writing this documenation... so the steps only go so far (though that is most of the way).

Download the `.bin` file ready on the a device with access to WLED - so on the same WiFi network, whether that is the WLED-AP or another network.

Open WLED controls page

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

Open WLED's `Config` menu

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

Open `Security and Updates`

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

Scroll down to the `Software Update` section and click `Manual OTA Update`

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

From this screen, click choose file and select the `.bin` file you saved in the first step

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

When your file is shown, click `Update` and stay on the webpage

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

Wait for it to go through these screens while updating:

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

If it fails, you will get this message - please contact us on info@mcqn.com to let us know it's gone wrong :/

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

huffeec, 2022-05-23:
I have managed to update to the local build of v0.13.1 using FTDI but not using OTA.
(But v0.13.1 doesn't seem to drive the lights?)

Once installed it's possible to use the OTA tool to write the local v0.11.1 or v0.13.1 bins, but not the versions from the main branch of WLED.

But if the v0.11.1 version is then flashed OTA it's not possible to use OTA to update to v0.13.1

I'm not sure why OTA isn't working on v0.11.1 but this suggest to me that FTDI is the only route to updating existing boards atm?

Is there value in updating the documentation to use FTDI, will users have access to USB to serial devices?

huffeec, 2022-05-23:
Eg
1.  Install esptool.py as described here https://docs.espressif.com/projects/esptool/en/latest/esp32/installation.html
2.  Download the latest build of the My Baby's got LED firmware
3.  Connect your board to USB using a USB to serial connector and the pins marked 'Serial' on your board.
4.  Set the board to programming mode by holding down reset, using a jumper wire to connect P0 to ground and releasing the reset button
5. From the command line run
`esptool.py --before default_reset --after hard_reset --chip esp8266 --port "/dev/ttyACM0" --baud 115200 write_flash 0x0 path/to/my-babys-got-led.bin`
NB Depending on your setup and OS the port description may be different

huffeec, 2022-05-25:
I've added a draft updatingFirmware.odt document but not referenced it anywhere yet. I will make these changes when the v0.13.1 bin is complete.

amcewen, 2022-06-15:
Digging into @huffeec's comment above:
>  (But v0.13.1 doesn't seem to drive the lights?)

This is because v0.13 removed the default relay pin, so the software doesn't turn on the power to the lights.  We should define it (to the old default setting of `12`) in our builds, and it looks like it might get configured as default when upgrading from earlier versions with the official WLED build(? Not 100% sure of this, but that seemed to be the case when upgrading one of our old boards over USB with the official v0.13.1)

If you end up with the wrong config, it can be fixed by...
1. Go into `LED Preferences` in config
2. Set `Relay GPIO` to 12, and make sure the `Invert` checkbox is ticked
3. `Save` those settings
4. Go back to the main screen
5. Turn the `Power` off and then back on (this seems to be needed to pick up the setting)

It all seems to be working now (I had a problem with the config getting corrupted, which I traced as far as the LittleFS `open` call failing, but an erase and reflash fixed things).

To use the stock WLED you need to choose one of the 2MB ESP8266 versions, so  `WLED_x_ESP02.bin`.  Wonder if that's why it fails on earlier builds of ours?

amcewen, 2023-11-15:
The OTA upload is working okay with the `ESP02.bin` versions until you get *beyond* `0.14.0-b1`.  At present any newer ones fail to upload - I'm not sure why at the moment.

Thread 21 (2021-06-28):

Fabricate programming/test rig

amcewen, 2021-06-28:
Spinning this out of #15 so we can knock off more self--contained issues...

Now that we've got the basics of the programming rig set up, we should laser-cut an https://tinylabs.io/openfixture/ jig to hold the board.

I'll need pogo pin points for the following connections:
 * T1
 * T2
 * 5V SB
 * TX
 * RX
 * GND
 * 0
 * PWR_ON_T1
 * 5V_T1
 * Data_T1
 * Clk_T1
 * 12
 * 13
 * 14

We might not use all of them right from the start, but if they're included then all the testing options will be open.

amcewen, 2021-07-26:
We should re-cut the top of the base, to sort out the minor (~1mm) alignment issue, then glue in the pogo pins.

If that fixes the flakiness of the programming (after I tested it initially last week) then this can be closed.

arthurrowland, 2021-07-28:
After some wild goose chase cutting new inserts, I noticed there was some slack in the interlocking construction of the rig, and pushing it to the bottom edge got things to line up pretty well!

The only pogo pin still looking a little off is the PWR_ON_T1 hole, so I'll drill the top panel out a little so there's enough play to hit the target when glued into place.

After that I'll bounce it back to @amcewen for testing with the hope we can close this issue.

arthurrowland, 2021-07-28:
Bouncing!

amcewen, 2021-08-11:
We've got all the pins we need for now working.  We can open a new issue if need be (or fold the fixing into whatever issue of testing that it relates to).

Closed 2021-08-11.

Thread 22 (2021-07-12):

Add keep-out area around mounting holes

amcewen, 2021-07-12:
It's not a big deal, but it would be handy to add an area around the mounting holes where there's no copper, to avoid it being exposed if some mounting screws were over-tightened and managed to damage the soldermask layer.

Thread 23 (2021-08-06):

Check why the mDNS name doesn't seem to get set up properly

amcewen, 2021-08-06:
This might be a bug in WLED, but raising it here for some initial investigation.  Setting the board's name in the settings doesn't always result in `name-you-chose.local` working to connect to the board.

arthurrowland, 2021-08-06:
Does [this WLED issue](https://github.com/Aircoookie/WLED/issues/762) or [this comment by aircoookie](https://github.com/Aircoookie/WLED/issues/1227#issuecomment-705108528) provide any clues?

Is the issue zeroconf support?

amcewen, 2021-08-13:
Have been digging into this off and on all week.  It *seems* that it's only a problem with programming it with Arduino rather than Platform IO.  An easy way to check if that's the problem would be if it also forgets any WiFi details if the board gets reset or power-cycled.

Older versions will be okay, but ones programmed with the latest versions of WLED (since it switched away from storing settings in EEPROM).

Programming it with the new rig is fine.  And it should be possible to upgrade the older ones over WiFi - I've not done that yet, but it would be useful to test and document.  We can get an updated `.bin` file from the programming rig, and then try the [instructions on the WLED wiki](https://github.com/Aircoookie/WLED/wiki/Install-WLED-binary)

Can I throw that over to you to try, @arthurrowland

arthurrowland, 2021-08-18:
I've been trying to get mDNS to work on windows with no luck, so far! Working assumption is that it is all ok on the board but Windows and Android don't support it out-of-the-box. Would be good to figure it out and let people know how to get it working.

arthurrowland, 2021-08-20:
I will uncritically install obscure software to try and solve a problem, and just tried [this software](https://hobbyistsoftware.com/bonjourbrowser), which initially found the IP address of the board I was using. But it didn't on the second attempt, and also didn't pick up the other boards on the network (such as the one connected to the electric liver bird). So not recommended. Could be operator error but it seems you're just supposed to open it up and refresh.

On a sort-of-related-but-probably-another-issue note, it would be great if [this node red module, wled2](https://flows.nodered.org/node/node-red-contrib-wled2), [github here](https://github.com/danecreekphotography/node-red-contrib-wled2), supported mDNS too - bit out of scope for me but would make guides easier to document since we wouldn't have to do a 'find out your board's IP address' step.

amcewen, 2021-08-20:
Yeah, that's the same Windows app I'd been using to look for instances - it seemed to work reasonably well, but I've also got Apple's Bonjour service installed on that Windows machine.

huffeec, 2022-02-16:
How often is "doesn't always"?
I've tried renaming mDNS through settings and not managed to recreate it exactly (I don't think)

Changing the name in settings alone doesn't take effect - old_name.local works but new_name.local doesn't
After a software power cycle the same - old_name.local works but new_name.local doesn't
Resetting the board via the push button does seem to work consistently** -new_name.local works but old_name.local doesn't

**I did have some confusion when after a power cycle old_name.local and new_name.local both seemed to work. Tested across different browsers and I think this is caching .

amcewen, 2022-02-16:
Maybe it's more of a behaviour-isn't-what-you'd-expect issue then?  In that it only changes the name after a power-cycle.

How did you do the "software power cycle"?  Was that with the power button on the UI?  I *think* that's just to turn the LEDs off and on, rather than reset the whole board... (again more of a UI issue but more of a bug in the upstream WLED stuff)

huffeec, 2022-02-16:
Yes to ui "software power cycle" which explains why it didn't have the same effect. Should I add this to the user instructions and then close this for now?

amcewen, 2022-02-21:
That sounds like a good plan.

Closed 2022-04-11.

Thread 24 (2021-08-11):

Find better solution for the power switch on the test jig

amcewen, 2021-08-11:
In testing the programming jig, it turns out that the [MIC2005A](http://www.farnell.com/datasheets/1670778.pdf) isn't sufficient for powering the board (I feared it might not be, but I already had one in stock and soldered onto a breakout board).

We need to find a different solution for high-side switching the 5V line (from 3V3 logic) to replace it.

amcewen, 2021-08-13:
I've ordered some [AP2191DWG-7](https://uk.farnell.com/diodes-inc/ap2191dwg-7/power-load-sw-high-side-2-1a-85deg/dp/3482828?ost=3482828), which should be good for 2.1A.

amcewen, 2021-09-13:
Have wired the new power switch up, and it seems to work okay.  However, once I'd programmed the board it dropped into a crash/reset loop rather than coming up cleanly.  Powering it up outside the jig it seemed fine.

Wonder if there's maybe not enough power from the power supply.  It'd be good to try with a beefier PSU, or trying a cap on the 5V line nearer to the board

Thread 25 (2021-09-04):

What about a bike version?

amcewen, 2021-09-04:
This'll be a new repo if I decide to do it, but I can log a few experiments for the initial prototyping here...

amcewen, 2021-09-04:
Tried 50 LEDs and they do a decent job of my crossbar and down to the bottle cage.  Push it up to 70 LEDs and that'll run past the bottle cage for the rest of the diagonal (and looks lots better).  90 LEDs will do the entire triangle of the frame.

WLED thinks the 90 LEDs are pulling 450mA running `glitter` pretty dimly, 1.2A at half-brightness (which is pretty nice indoors on a dull day) and 1.5A at full brightness.

Pimoroni have a 13400mAh Li-ion battery, which would still give a decent running time...

The battery and PCB would sit quite nicely behind the seatpost too.

amcewen, 2021-12-29:
Spun out as its own repo: [my-bikes-got-led](https://github.com/mcqn/my-bikes-got-led/)

Closed 2021-12-29.

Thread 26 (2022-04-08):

Can connecting LEDs the wrong way round kill the LEDs?

amcewen, 2022-04-08:
I don't think it should be catastrophic if you connect the LEDs the wrong way round, but there are two of the reels of 5m LEDs we bought recently that have faults on the first LED or first few LEDs where they illuminate white.

On the reel with a few white LEDs, the rest all function fine.  On the reel with a single white LED the rest don't illuminate.

It's possible the LEDs were just DOA, but there's a small chance they failed when they were connected up backwards (which possibly blew the fuse on the board too)

It'd be good to check (we can use the single-white-LED reel, as that'll need the first LED cutting off anyway) if that's the case.

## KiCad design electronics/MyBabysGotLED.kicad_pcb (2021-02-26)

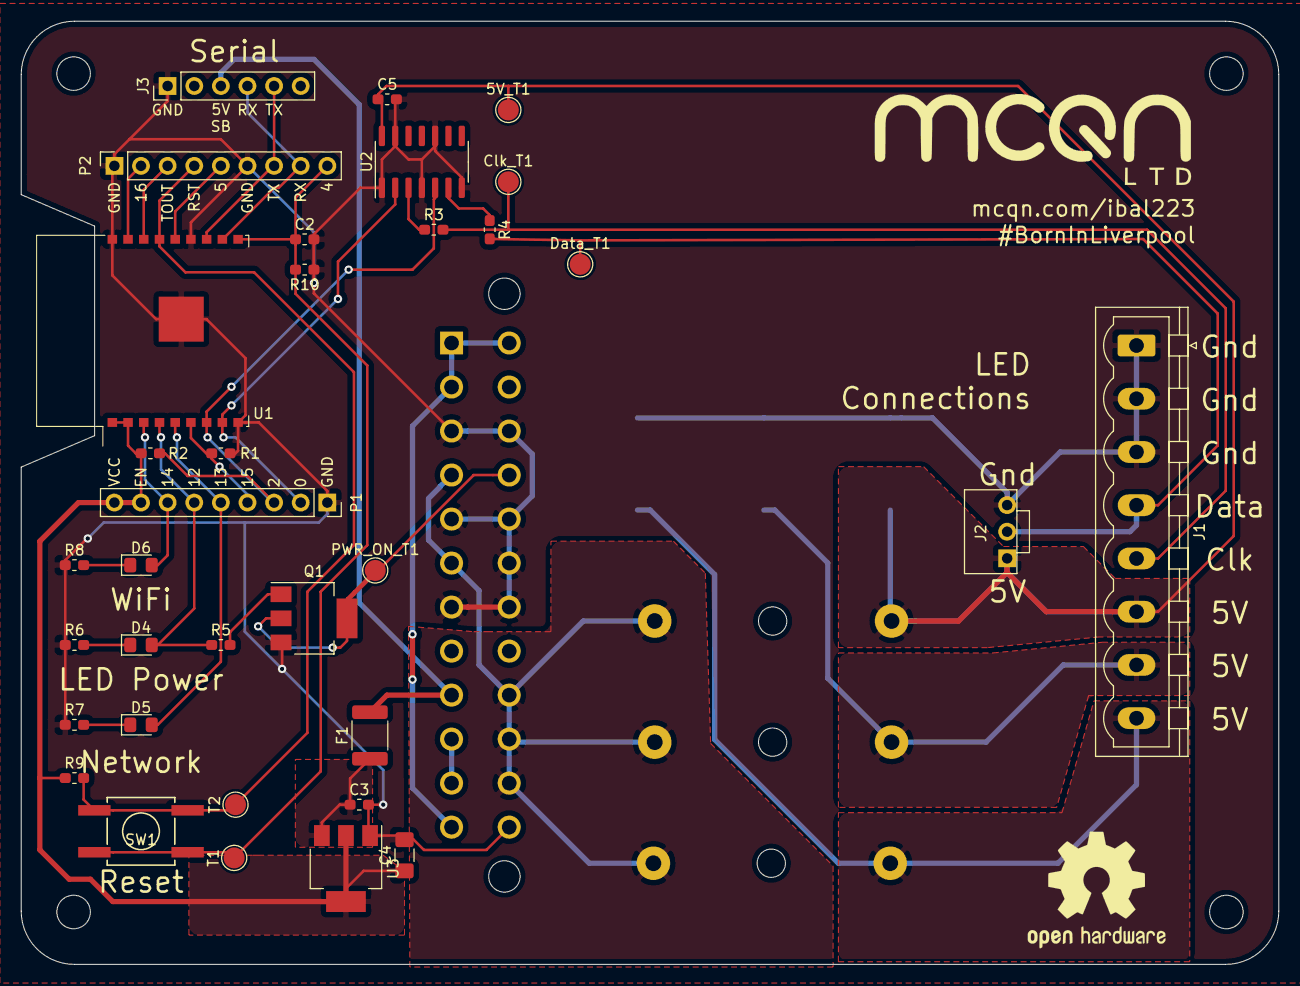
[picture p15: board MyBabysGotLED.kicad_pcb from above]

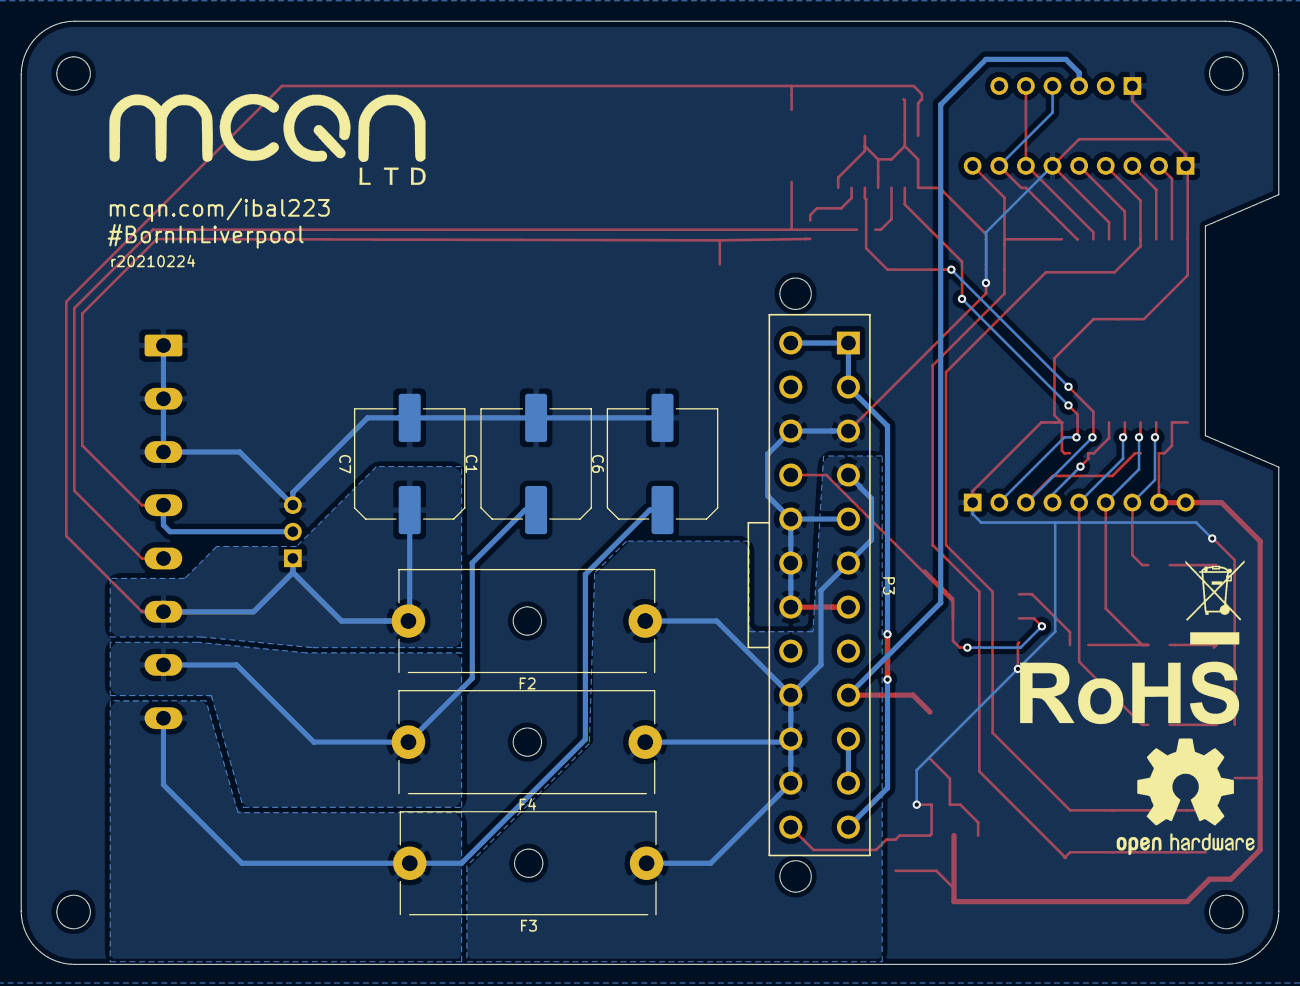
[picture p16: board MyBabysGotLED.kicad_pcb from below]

Board: 2 copper layers, 120.0 x 90.0 mm, 41 parts (7 on the bottom side), 32 nets.

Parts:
5V_T1: Conn_01x01; TestPoint_Pad_D2.0mm
C1, C6, C7: 470uF; C_Elec_10x10.2
C2: C47nF; C_0603_1608Metric_Pad1.05x0.95mm_HandSolder
C3, C5: 0.1uF; C_0603_1608Metric_Pad1.05x0.95mm_HandSolder
C4: 10uF; C_1206_3216Metric_Pad1.42x1.75mm_HandSolder
Clk_T1: Conn_01x01; TestPoint_Pad_D2.0mm
D4, D5, D6: LED; LED_0805_2012Metric_Pad1.15x1.40mm_HandSolder
Data_T1: Conn_01x01; TestPoint_Pad_D2.0mm
F1: Polyfuse; Fuse_1812_4532Metric_Pad1.30x3.40mm_HandSolder
F2, F3, F4: Fuse; Fuseholder_Cylinder-5x20mm_Wurth_WR-FSH_Horizontal
J1: APA102; PhoenixContact_MSTBVA_2,5_8-G-5,08_1x08_P5.08mm_Vertical
J2: WS2812; PinHeader_1x03_P2.54mm_Vertical
J3: Serial; PinHeader_1x06_P2.54mm_Vertical
P1, P2: CONN_01X09; PinSocket_1x09_P2.54mm_Vertical
P3: ATX_Power_2x12_Connector; Molex_44206-0007_socket_(ATX_power)
PWR_ON_T1: Conn_01x01; TestPoint_Pad_D2.0mm
Q1: NJT4031NT1G; SOT-223-3_TabPin2
R1, R2, R10: R10k; R_0603_1608Metric_Pad1.05x0.95mm_HandSolder
R3, R4, R5: 470R; R_0603_1608Metric_Pad1.05x0.95mm_HandSolder
R6, R7, R8, R9: R560; R_0603_1608Metric_Pad1.05x0.95mm_HandSolder
SW1: Reset; SW_SPST_GULLWING
T1, T2: CONN_01X01; TestPoint_Pad_D2.0mm
U1: ESP-13-WROOM-02; ESP-WROOM-02
U2: SN74AHCT125; SOIC-14_3.9x8.7mm_P1.27mm
U3: LM1117-3.3; SOT-223-3_TabPin2

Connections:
+3V3: C4.1, P1.8, P1.9, R2.1, R9.1, U1.1, U1.2, U3.2
+5V: F2.1, F3.1, F4.1, P3.4, P3.6, P3.21, P3.22, P3.23
/BaseESP8266/IO4: C2.1, P2.9, R10.2, SW1.1, T1.1, U1.10
/BaseESP8266/IO5: P2.5, U1.14
/BaseESP8266/IO12: D4.2, P1.6, R5.1, U1.4
/BaseESP8266/IO13: D5.2, P1.5, U1.5
/BaseESP8266/IO14: D6.2, P1.7, U1.3
/BaseESP8266/IO15: P1.4, R1.2, U1.6
/BaseESP8266/IO16: P2.2, U1.17
/BaseESP8266/RST: P2.4, R9.2, SW1.2, T2.1, U1.15
/BaseESP8266/RXD: J3.4, P2.8, U1.11
/BaseESP8266/TOUT: P2.3, U1.16
/BaseESP8266/TXD: J3.5, P2.7, U1.12
GND: C1.2, C2.2, C3.2, C4.2, C5.2, C6.2, C7.2, J1.1, J1.2, J1.3, J2.3, J3.1, P1.1, P2.1, P2.6, P3.3, P3.5, P3.7, P3.15, P3.17, P3.18, P3.19, P3.24, Q1.3, R1.1, R6.1, R7.1, R8.1, R10.1, U1.9, U1.13, U1.18, U1.19, U2.1, U2.4, U2.7, U2.10, U2.13, U3.1
LED_Clk: P1.2, U1.8, U2.2
LED_Data: P1.3, R2.2, U1.7, U2.5
unnamed: 5V_T1.1, C5.1, C7.1, F2.2, J1.6, J2.1, U2.14
unnamed: C1.1, F4.2, J1.7
unnamed: C3.1, F1.1, U3.3
unnamed: C6.1, F3.2, J1.8
unnamed: Clk_T1.1, J1.5, R3.2
unnamed: D4.1, R6.2
unnamed: D5.1, R7.2
unnamed: D6.1, R8.2
unnamed: Data_T1.1, J1.4, J2.2, R4.2
unnamed: F1.2, J3.3, P3.9
unnamed: P3.1, P3.2, P3.12, P3.13
unnamed: P3.10, P3.11
unnamed: P3.16, PWR_ON_T1.1, Q1.2
unnamed: Q1.1, R5.2
unnamed: R3.1, U2.3
unnamed: R4.1, U2.6

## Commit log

2020-10-28 Most of schematic laid out. Part of #3, and first pass at #2
    [BaseESP8266.sch, MyBabysGotLED.kicad_pcb, MyBabysGotLED.sch]
2020-10-28 Most of BoM details added. Part of #4
    [1-click-bom.tsv, BaseESP8266.sch, MyBabysGotLED.kicad_pcb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]
2020-11-04 PCB laid out. Final part of #3 and all of #5
    [MyBabysGotLED.kicad_pcb, MyBabysGotLED.sch]
2020-11-06 Update purchase details to PayPal, while we wait for PCBs to arrive for the photo for the Tindie store.
2020-11-06 Add a picture of the finished PCB
2021-02-17 Update one of the caps to cut-tape part rather than full reel. Other minor tweaks.
    [BaseESP8266.sch, MyBabysGotLED.kicad_pcb]
2021-02-26 Board mods to use lower value fuses (rather than a single large fuse). Fixes #14
    * Three 5V/Gnd feeds rather than one, each protected with a 5x20mm 8A fuse
    * 470uF smoothing caps on the 5V lines, rather than a single 1000uF
    * New test points for 5V, data and clock lines
    [MyBabysGotLED.kicad_pcb, MyBabysGotLED.sch]
2021-03-07 BoM updates after #14 was fixed (and to add a couple of items missed off earlier)
    [1-click-bom.tsv]
2021-03-07 Correct Farnell part number for the terminal block
    [1-click-bom.tsv, MyBabysGotLED.sch]
2021-03-17 Add mounting plate (for MBGLv1 boards!). Part of #7
2021-05-17 Updated photos and OSHW mark
    [mounting-plate.dxf]
2021-07-13 Renamed ATX mounting plate and added sandwich enclosure
    The sandwich enclosure needs 20mm standoffs for the power side and 10mm standoffs for the LED and status light side.
    [ATX-PS2-mounting-plate.dxf]
2021-07-13 Made filenames more specific
    [my-babys-got-LED-rev1_mounting-plate_ATX-PS2.dxf]
2021-07-27 Added & updated mounting boards
    Added one-side board; updated other options after manufacturing them to check dimensions and files; included laser-ready dxf files as well as SVGs; and added some explanatory text in the design files.
    [my-babys-got-LED-rev1_mounting-plate_ATX-PS2.dxf, my-babys-got-LED_mounting-plate_PSU-ATX-PS2_dxf-for-laser-cutting.dxf, my-babys-got-LED_mounting-plate_one-si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]
2022-04-11 Added board reset to change mDNS name to instructions as #23
